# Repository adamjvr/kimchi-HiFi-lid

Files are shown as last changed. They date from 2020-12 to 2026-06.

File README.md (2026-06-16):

# Kimchi HiFi Lid — SGTL PCB

This directory contains the KiCad hardware files for the **SGTL5000-based audio PCB variant** of the Kimchi HiFi Lid project.

The board is an audio codec / interface PCB intended to mate with the main Kimchi hardware through high-density board-to-board connectors. It includes the audio codec, clocking, analog I/O connectors, EEPROM, local power filtering, and supporting passives required for the SGTL audio path.

## Design overview

Primary design intent:

- Provide a compact audio codec board for the Kimchi HiFi Lid assembly.
- Interface the audio codec and related signals to the parent system through two 60-pin Hirose board-to-board connectors.
- Break out analog audio through RCA and 3.5 mm audio connectors.
- Provide local clocking, EEPROM, level/interface support, and power filtering around the codec.

## Main functional blocks

- **Audio codec:** `U2` — `SGTL5000XNLA3`, NXP SGTL5000 stereo audio codec.
- **Clock source:** `X1` — `ASFL1-12.288MHZ-EC-T`, 12.288 MHz oscillator.
- **EEPROM:** `U1` — `24C32` / `M24C32-FMC6TG` I²C EEPROM.
- **Board-to-board connectors:** `J2`, `J3` — `DF40HC(3.5)-60DS` 60-pin connectors.
- **Analog audio I/O:**
  - `J1`, `J4` — `RCJ-2123` RCA jacks.
  - `J5` — `54-00176` 3.5 mm audio jack.
  - `MIC_IN` and `MIC_BIAS` nets for microphone input support.
- **Logic support:** `U3` — `SN74LV1T34DBVRG4` single-bit buffer / level interface.
- **Power rails and filtering:** `VDD_5V`, `VDD_3V3`, `VDD_1V8`, ferrite beads, bulk capacitance, and local bypassing.

## Directory contents

| Path | Purpose |
|---|---|
| `kimchi_ulid.sch` | Main KiCad / Eeschema schematic. |
| `kimchi_ulid.sch-bak` | Backup copy of the schematic. |
| `kimchi_ulid.lib` | Local symbol library. |
| `kimchi_ulid-cache.lib` | Cached schematic symbols. |
| `kimchi_ulid.dcm` | KiCad symbol documentation metadata. |
| `kimchi_ulid.csv` | BOM / component export. See warning below before ordering. |
| `kimchi_ulid.xml` | KiCad-generated netlist / BOM source export. |
| `kimchi_ulid.pretty/` | Local KiCad footprints and related 3D assets. |
| `gerber/` | Exported manufacturing files. |
| `sym-lib-table` | KiCad symbol library table. |
| `fp-lib-table` | KiCad footprint library table. |

## KiCad version notes

This project uses the older KiCad / Eeschema file format, with the schematic stored as `kimchi_ulid.sch`.

For editing in a newer KiCad release:

1. Open the project/schematic in KiCad.
2. Let KiCad convert legacy schematic/library data if prompted.
3. Save the converted project on a new branch before overwriting the original files.
4. Re-run ERC, DRC, BOM export, and Gerber generation after conversion.

## Fabrication notes

The `gerber/` directory contains exported fabrication data, including copper, solder mask, silkscreen, fabrication, and edge-cut files.

Before sending this board out for manufacture, regenerate the manufacturing package from the current KiCad project and verify:

- Board outline and mounting holes.
- Layer stackup, especially the inner copper layers.
- DF40 connector orientation, stack height, and mating-board alignment.
- RCA and 3.5 mm jack mechanical clearance.
- Power rail assignments from the parent board.
- Audio routing, grounding, and codec analog supply filtering.
- I²C / digital audio signal mapping to the parent processor.

## Important BOM warning

The schematic in this SGTL folder uses `SGTL5000XNLA3` for `U2`, but the checked-in `kimchi_ulid.csv` may be stale and may still list `U2` as `WM8750CJLGEFL` from an earlier codec revision.

Do **not** order directly from the CSV without regenerating the BOM from the current schematic.

Recommended release process:

1. Open the schematic in KiCad.
2. Confirm `U2` is the intended SGTL5000 part.
3. Regenerate the BOM / CSV from the active schematic.
4. Compare the regenerated BOM against the committed `kimchi_ulid.csv`.
5. Update the CSV before fabrication or assembly.

## Bring-up checklist

Suggested first-power and validation flow:

- Inspect the board for solder bridges, especially around the codec QFN and DF40 connectors.
- Verify no shorts on `VDD_5V`, `VDD_3V3`, `VDD_1V8`, and ground before power-up.
- Power the board from a current-limited bench supply or through the intended parent board with current monitoring.
- Confirm local rails are present and stable.
- Confirm the 12.288 MHz oscillator output.
- Verify I²C communication with the codec and EEPROM.
- Confirm codec reset / enable behavior if controlled by the parent system.
- Test analog output at low level first, then validate full-scale playback.
- Test microphone input and bias only after confirming the audio codec is enumerating/configuring correctly.

## Status

Hardware design files and generated manufacturing outputs are present, but this directory should be treated as an engineering design package rather than a guaranteed production release. Regenerate and review all release outputs before ordering boards or parts.

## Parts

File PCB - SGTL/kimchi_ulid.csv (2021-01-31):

Reference | Quantity | Value | Footprint | Datasheet | Mfgr | Part | Vendorpart | Cost QTY: 1 | Cost QTY: 1000 | Cost QTY: 10000 | Cost QTY: 2500 | Cost QTY: 5000 | Date Created | Date Modified | Description | Designer | Height | Lead-Free ? | MFR | MFR# | Management_ID | Mounting | Package | Pin Count # | RoHS Levels | Status | Tolerance | Type | Vendor | Vendor # | Voltage | _Value_ | Cost QTY: 3000
C10 C12 | 2 | T491D227M010AT | kimchi_ulid:T491D227M010AT | https://api.kemet.com/component-edge/download/datasheet/T491D227M010AT.pdf |  |  |  | 1.36000 | 0.53786 | * | 0.50200 | 0.48408 | 12/16/2020 | 12/16/2020 | 220µF Molded Tantalum Capacitors 10V 2917 (7343 Metric) 500mOhm | AVR | 3.10mm | Yes | KEMET | T491D227M010AT | * | SMT | 2917 | 2 | 1 | Active | 10% | Tantalum Cap | Digikey | 399-9744-2-ND | 10VDC | 220uF
C1 C2 C15 C16 C17 | 5 | T491A105K010AT | kimchi_ulid:C1206 | https://www.digikey.com/htmldatasheets/production/2487974/0/0/1/t491-series.html |  |  |  | 0.30000 | 0.07980 | 0.06720 | * | * | 12/9/2020 | 12/9/2020 | 1µF Molded Tantalum Capacitors 10V 1206 (3216 Metric) | AVR | 0.55mm | Yes | KEMET | T491A105K010AT | * | SMT | 1206 | 2 | 1 | Active | 10% | Ceramic Cap | Digikey | 399-9449-2-ND | 10V | 1uF
C25 | 1 | UZP1H0R1MCL1GB | kimchi_ulid:UZP1H0R1MCL1GB | https://media.digikey.com/pdf/Data%20Sheets/Nichicon%20PDFs/ZP_Series.pdf |  |  |  | 0.71000 | 0.20706 | 0.17052 | * | * | 12/16/2020 | 12/16/2020 | 0.1µF 50V Aluminum Electrolytic Capacitors Radial, Can - SMD 2000 Hrs @ 85°C | AVR | 4.6mm | Yes | Nichicon | UZP1H0R1MCL1GB | * | SMT | * | 2 | 1 | Active | 20% | Aluminum Cap | Digikey | 493-10087-2-ND | 50V | 0.1uF
C3 C4 C5 C6 C7 C8 C11 C14 C18 C24 | 10 | C0402C104K9PACTU | kimchi_ulid:C0402 | https://content.kemet.com/datasheets/KEM_C1006_X5R_SMD.pdf |  |  |  | 0.10000 | 0.01139 | 0.00756 | 0.01035 | 0.00952 | 12/7/2019 | 12/7/2019 | 0.1µF ±10% 6.3V Ceramic Capacitor X5R 0402 (1005 Metric) | AVR | 0.55mm | Yes | KEMET | C0402C104K9PACTU | * | SMT | 0402 | 2 | 1 | Active | 10% | Ceramic Cap | Digikey | 399-3026-6-ND | 6.3V | 0.1uF
C9 C13 C19 C20 C21 C22 C23 | 7 | T494A106M006AT | kimchi_ulid:T494A106M006AT | https://api.kemet.com/component-edge/download/datasheet/T494A106M006AT.pdf |  |  |  | 0.69000 | 0.23100 | * | 0.23100 | * | 12/16/2020 | 12/16/2020 | 10µF Molded Tantalum Capacitors 6.3V 1206 (3216 Metric) 2Ohm | AVR | 1.8mm | Yes | KEMET | T494A106M006AT | * | SMT | 1206 | 2 | 1 | Active | 20% | Tantalum Cap | Digikey | 399-9757-2-ND | 6.3V | 10uF
FB1 FB2 FB3 FB4 FB5 FB6 FB7 | 7 | FBMJ1608HM180NTR | kimchi_ulid:R0603 | https://www.yuden.co.jp/productdata/catalog/chipbeads01_e.pdf |  |  |  | 0.11000 | 0.03135 | * | 0.02660 | 0.02850 | 12/5/2019 | 12/5/2019 | 18 Ohms @ 100MHz 1 Power Line Ferrite Bead 0603 (1608 Metric) 7.5A 4mOhm | AVR | 1mm | Yes | Taiyo Yuden | FBMJ1608HM180NTR | * | SMT | 0603 | 2 | 1 | Active | * | Ferrite Bead | Digikey | 587-3251-1-ND | * | FBMJ1608HM180NTR
H1 H2 H3 H4 | 4 | MountingHole_Pad | kimchi_ulid:MountingHole_3mm_Pad | ~
J1 J4 | 2 | RCJ-2123 | kimchi_ulid:RCJ-2123 | https://www.cuidevices.com/product/resource/digikeypdf/rcj-21xx.pdf |  |  |  | 1.67000 | 0.93000 | * | 0.86800 | * | 12/14/2020 | 12/14/2020 | 3.20mm ID, 9.00mm OD (RCA) Phono (RCA) Jack Mono Connector Solder | AVR | 5.12mm | Yes | CUI Devices | RCJ-2123 | * | ThroughHole Right Angle | * | 4 | 1 | Active | * | RCA Jack | Digikey | CP-1432-ND | 24VDC | RCJ-2123
J2 J3 | 2 | DF40HC(3.5)-60DS | kimchi_ulid:DF40HC(3.5)-60DS | ~
J5 | 1 | 54-00176 | kimchi_ulid:54-00176 | http://www.kycon.com/2013Catalogpage/USB/KUSBX.pdf |  |  |  | 0.91000 | 0.49600 | 0.41230 |  | 0.43400 | 12/8/2020 | 12/8/2020 | 3.50mm (0.141 | 1/8" | Mini Plug) - Headphone Phone Jack Stereo (4 Conductor | TRRS) Connector Solder" | AVR | 4mm | Yes | Tensility International Corp | 54-00176 | * | ThroughHole Right Angle | 3.5mm Audio | 6 | 1 | Active | * | 3.5mm Audio | Digikey | 839-54-00176TR-ND | * | 54-00176 | 0.44950
J6 | 1 | Conn_01x03_Male | Pin_Headers:Pin_Header_Straight_1x03_Pitch2.54mm | ~
LOGO1 | 1 | Logo_Open_Hardware_Small | Symbol:OSHW-Logo_5.7x6mm_SilkScreen | ~
R1 | 1 | RC0402JR-072K2L | AVR-KiCAD-Lib-Resistors:R0402 | https://www.yageo.com/upload/media/product/productsearch/datasheet/rchip/PYu-RC_Group_51_RoHS_L_11.pdf |  |  |  | 0.10000 | 0.00212 | 0.00132 | 0.00184 | 0.00152 | 12/10/2020 | 12/10/2020 | 2.2 kOhms ±5% 0.063W, 1/16W Chip Resistor 0402 (1005 Metric) Thick Film | AVR | 0.4mm | Yes | Yageo | RC0402JR-072K2L | * | SMT | 0402 | 2 | 1 | Active | 1% | Thick Film Resistor | Digikey | 311-2.2KJRCT-ND | * | 2.2K
R2 | 1 | RC0603FR-0747KL | AVR-KiCAD-Lib-Resistors:R0603 | https://www.yageo.com/upload/media/product/productsearch/datasheet/rchip/PYu-RC_Group_51_RoHS_L_10.pdf |  |  |  | 0.10000 | 0.00421 | 0.00238 | 0.00366 | 0.00274 | 6/18/2020 | 6/18/2020 | 47 kOhms ±1% 0.1W, 1/10W Chip Resistor 0603 (1608 Metric) Moisture Resistant Thick Film | AVR | 0.55m | Yes | Yageo | RC0603FR-0747KL | * | SMT | 0603 | 2 | 1 | Active | 1% | Resistor | Digikey | 311-47.0KHRCT-ND | * | 47K
U1 | 1 | 24C32 | Package_DFN_QFN:DFN-8-1EP_3x2mm_P0.5mm_EP1.36x1.46mm | http://www.st.com/content/ccc/resource/technical/document/datasheet/80/4e/8c/54/f2/63/4c/4a/CD00001012.pdf/files/CD00001012.pdf/jcr:content/translations/en.CD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 | ST | M24C32-FMC6TG | 497-15757-1-ND
U2 | 1 | WM8750CJLGEFL | kimchi_ulid:QFN-32_EP_5x5_Pitch0.5mm | https://d3uzseaevmutz1.cloudfront.net/pubs/proDatasheet/WM8750JL_v4.1.pdf |  |  |  | 5.59000 | 2.80630 | * | 2.70080 | 2.61640 | 12/15/2020 | 12/15/2020 | Stereo Audio Interface 24 b 32-QFN (5x5) | AVR | 1.1mm | Yes | Cirrus Logic Inc. | WM8750CJLGEFL | * | SMT | QFN | 32 | 1 | Active | * | Audio Codec | Digikey | 598-2392-ND | 3.3V | WM8750CJLGEFL
U3 | 1 | SN74LV1T34DBVRG4 | kimchi_ulid:SOT-23-5 | http://www.ti.com/general/docs/suppproductinfo.tsp?distId=10 |  |  |  | 0.45000 | 0.14040 | * |  | * | 12/10/2020 | 12/10/2020 | Buffer, Non-Inverting 1 Element 1 Bit per Element Push-Pull Output SOT-23-5 | AVR | 1.11mm | Yes | Texas Instruments | SN74LV1T34DBVRG4 | * | SMT | SOT23-5 | 5 | 1 | Active | * | Buffer | Digikey | 296-SN74LV1T34DBVRG4CT-ND | 3.3V | SN74LV1T34DBVRG4 | 0.12870
X1 | 1 | ASFL1-12.288MHZ-EC-T | kimchi_ulid:ASFL1 | https://abracon.com/Oscillators/ASFL1.pdf |  |  |  | 1.14000 | 0.75048 | 0.66144 | * | 0.68688 | 12/10/2020 | 12/10/2020 | 12.288MHz XO (Standard) HCMOS, TTL Oscillator 3.3V Enable/Disable 4-SMD, No Lead | AVR | 4.4mm | Yes | Abracon LLC | ASFL1-12.288MHZ-EC-T | * | SMT | Proprietary | 4 | 1 | Active | * | Crystal | Digikey | 300-8245-1-ND | 3.3V | ASFL1-12.288MHZ-EC-T

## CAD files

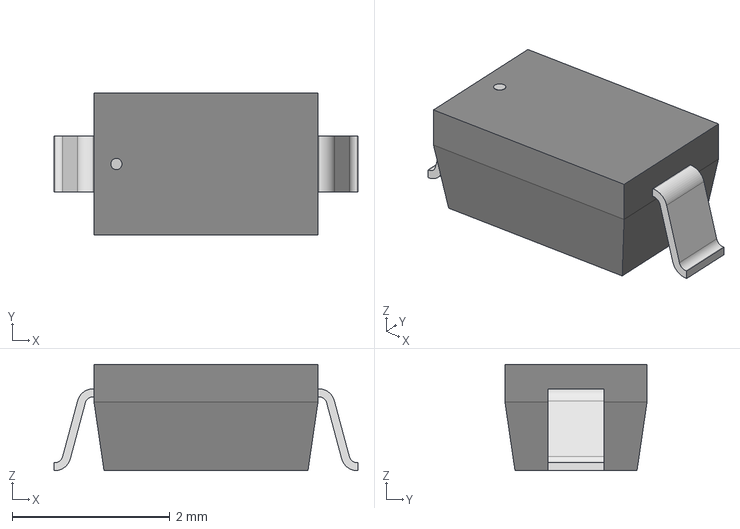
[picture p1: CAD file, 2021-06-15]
PCB - SGTL/3D/SOD-123_ONS.step
3.86 x 1.80 x 1.35 mm

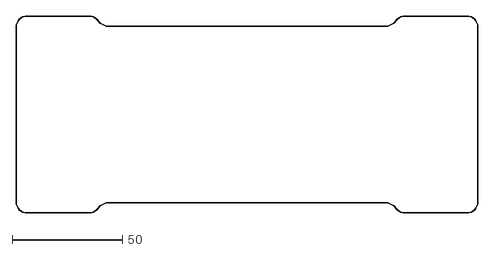
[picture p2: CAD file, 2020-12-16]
PCB - SGTL/Shape_Mockup.dxf
209.3 x 89.3

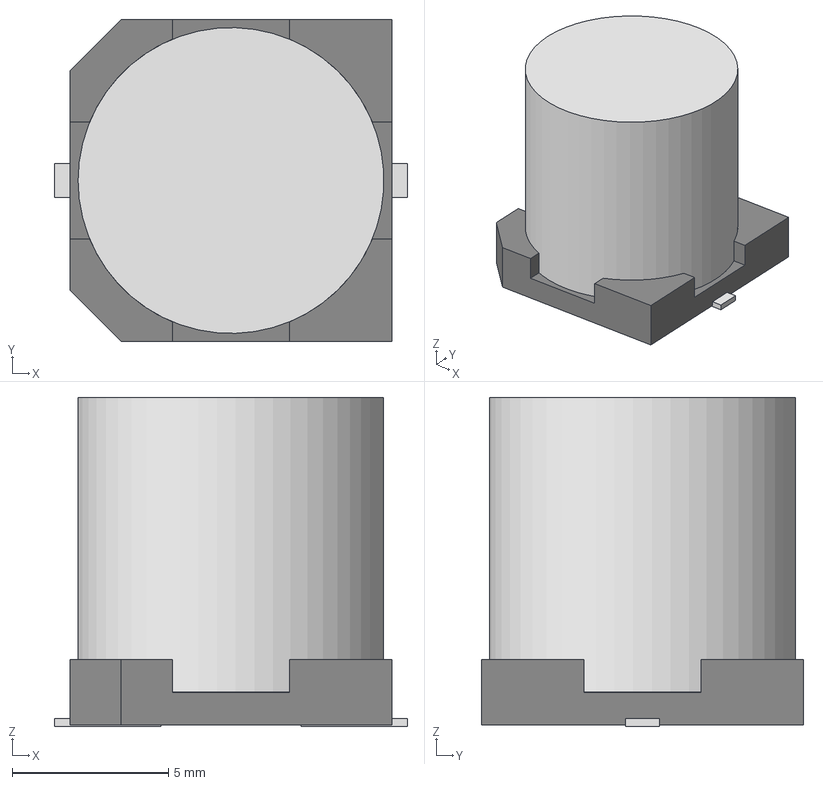
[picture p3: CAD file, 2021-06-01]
PCB - SGTL/3D/CAP_UCD_10X10_NCH.step
11.3 x 10.3 x 10.5 mm

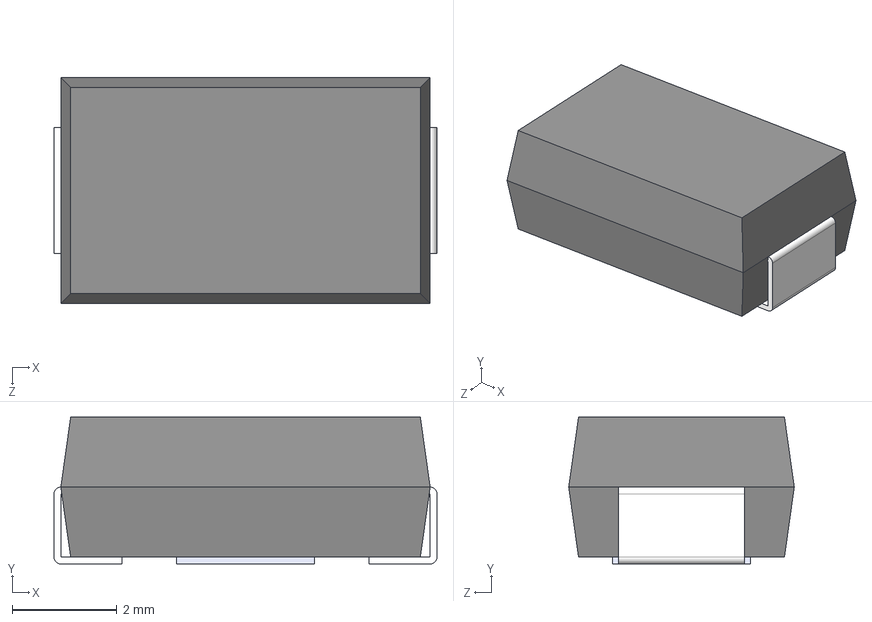
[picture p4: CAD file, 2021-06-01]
PCB - SGTL/3D/T491D106K020AT.STEP
7.30 x 2.80 x 4.30 mm

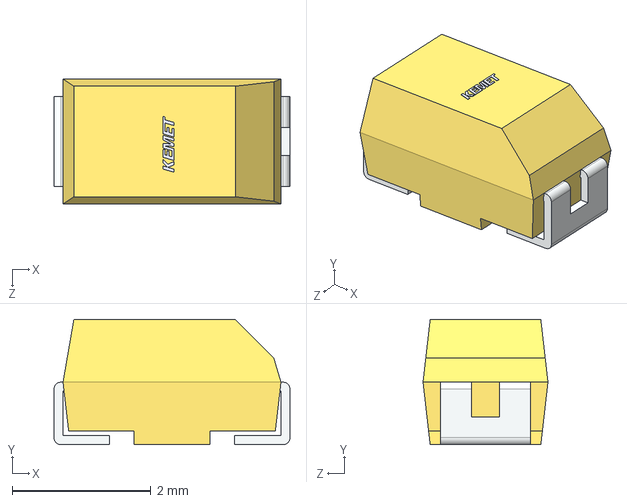
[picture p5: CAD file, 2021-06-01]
PCB - SGTL/3D/CTSM_TCM2NK_3216_L3.STEP
3.40 x 1.81 x 1.80 mm

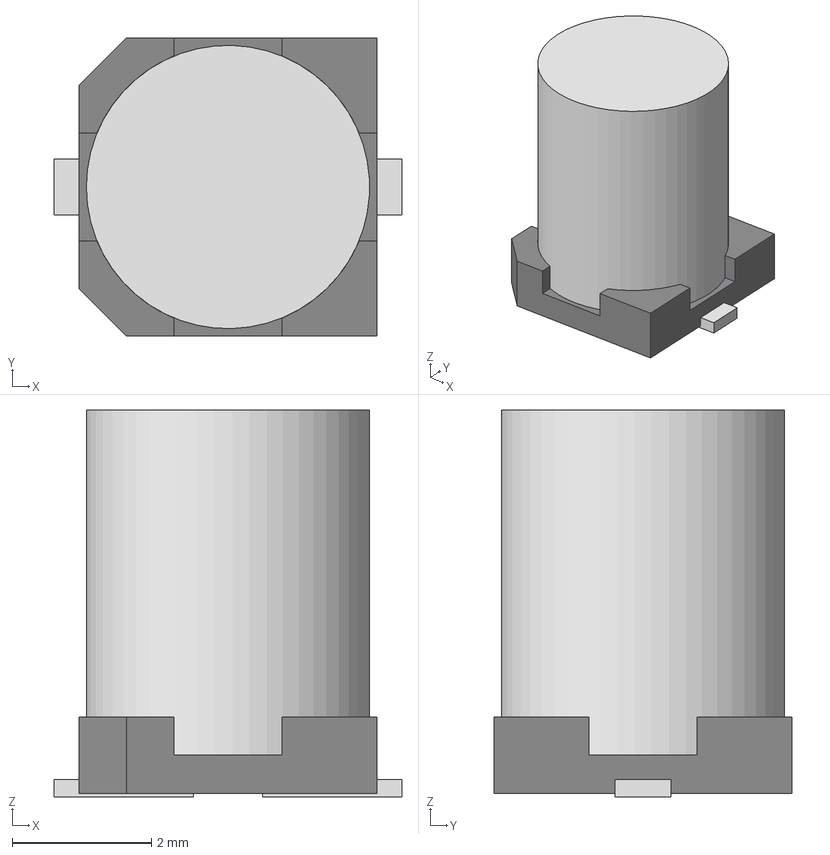
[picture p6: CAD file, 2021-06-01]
PCB - SGTL/3D/CAP_UUQ_4X5P4_NCH.step
5.00 x 4.29 x 5.57 mm

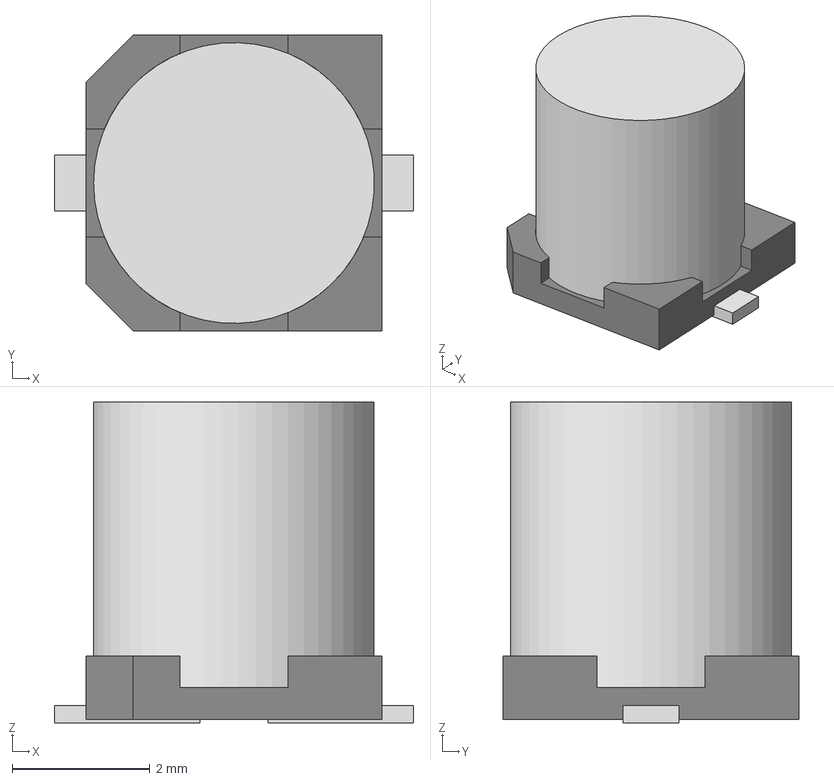
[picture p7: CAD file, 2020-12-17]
PCB - SGTL/3D/CAP_UZP_4X4P5_NCH.step
5.21 x 4.29 x 4.65 mm

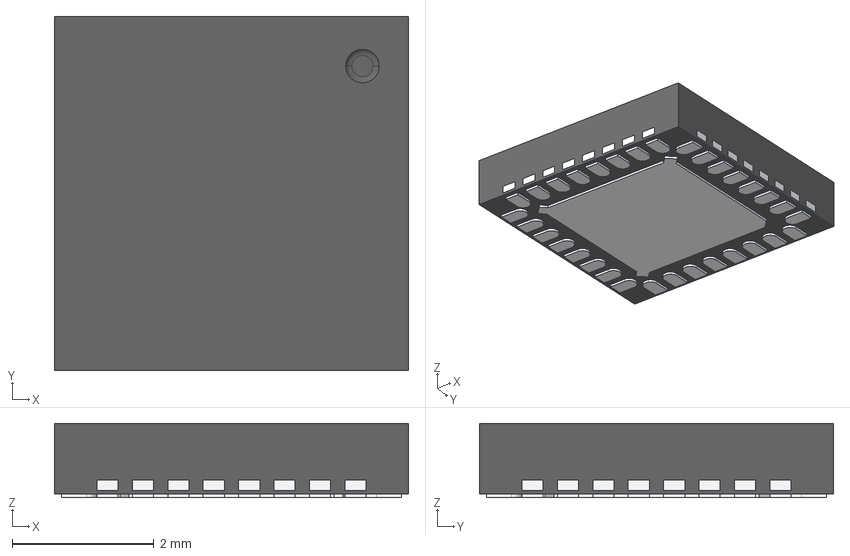
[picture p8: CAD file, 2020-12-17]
PCB - SGTL/3D/QFN-32 V6.stp
5.00 x 5.00 x 1.05 mm

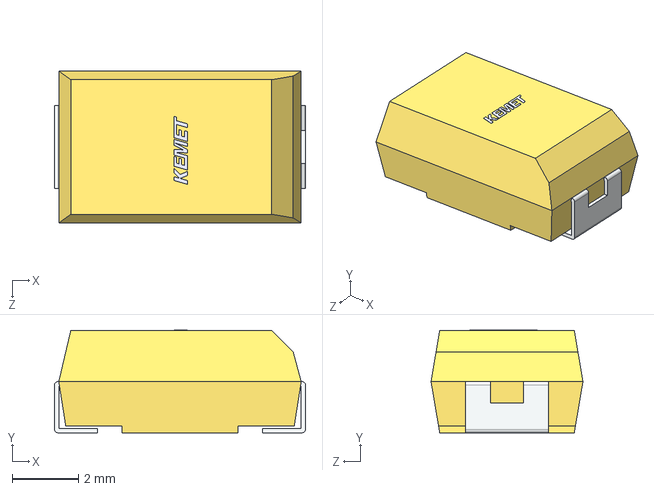
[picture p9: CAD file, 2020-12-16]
PCB - SGTL/3D/CTSM_TCM2NK_7343_L7.STEP
7.60 x 3.11 x 4.60 mm

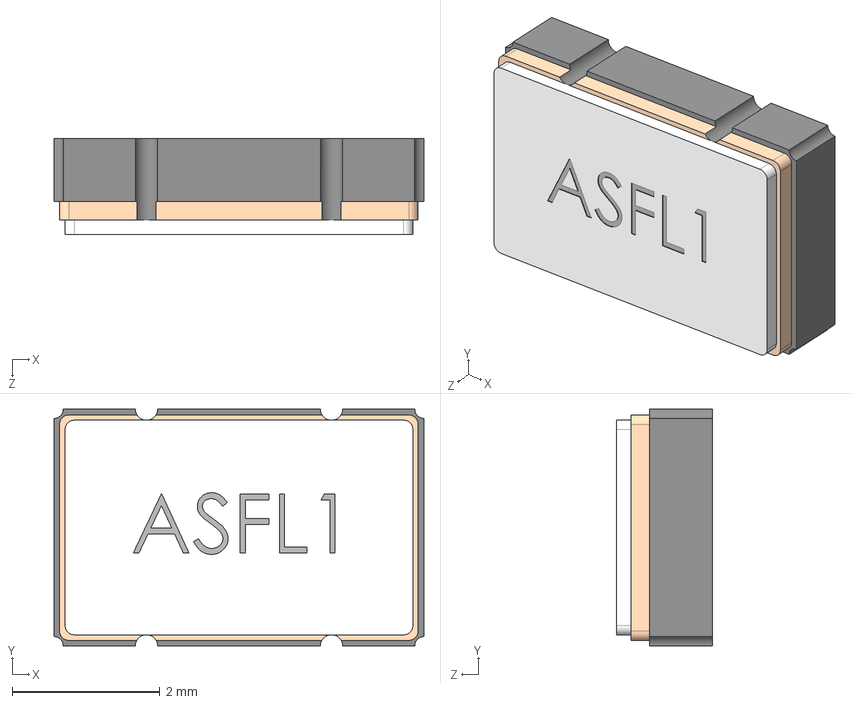
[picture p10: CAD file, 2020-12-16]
PCB - SGTL/3D/ASFL1.STEP
5.00 x 3.20 x 1.30 mm

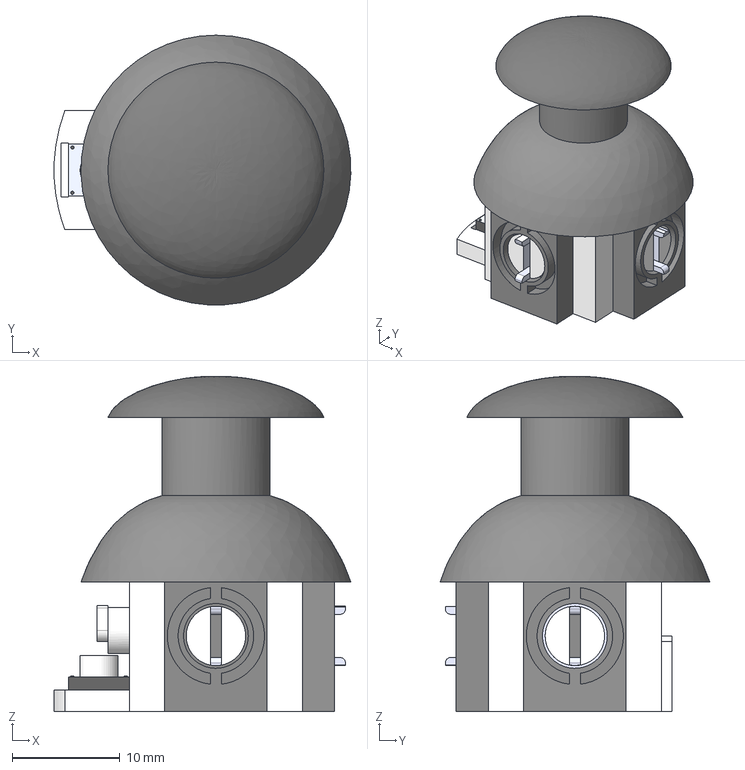
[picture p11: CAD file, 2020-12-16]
PCB - SGTL/3D/Joystick HW504 Board.step
27.5 x 25.0 x 31.0 mm

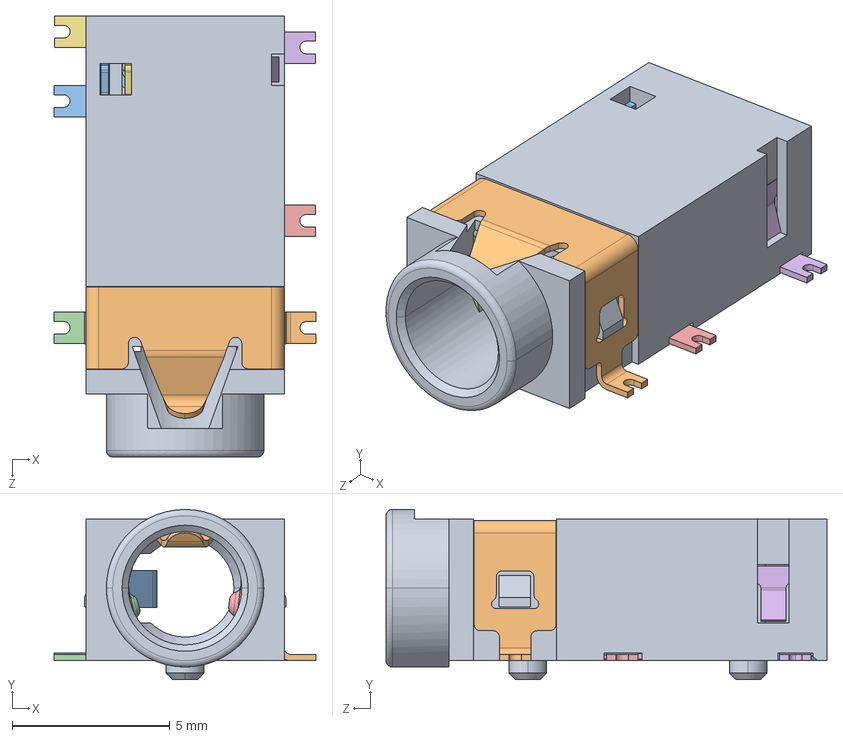
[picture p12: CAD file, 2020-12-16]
PCB - SGTL/3D/54-00177.STEP
8.31 x 5.40 x 14.0 mm
54-00177_insulator
54-00177_#1
54-00177_#4
54-00177_#2
54-00177_#3
54-00177_#6
54-00177_#5

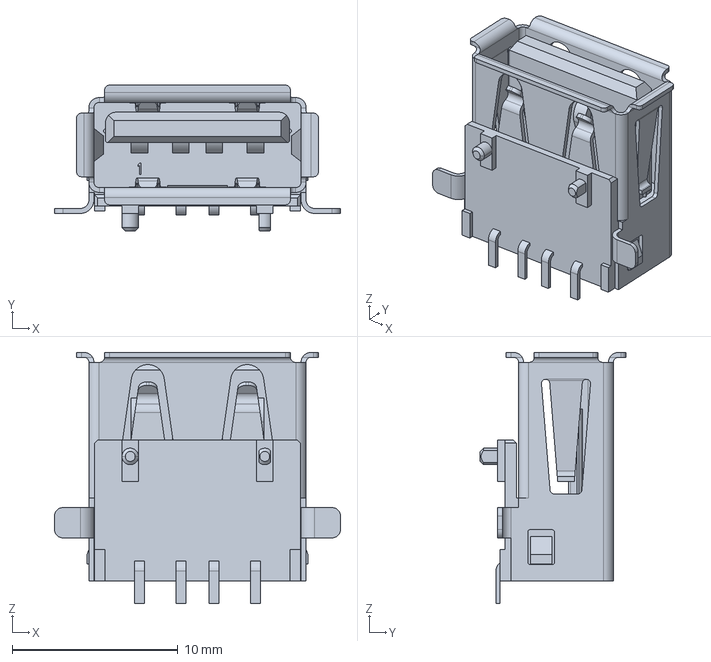
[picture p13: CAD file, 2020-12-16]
PCB - SGTL/3D/1-292303-6.stp
17.3 x 8.79 x 15.2 mm

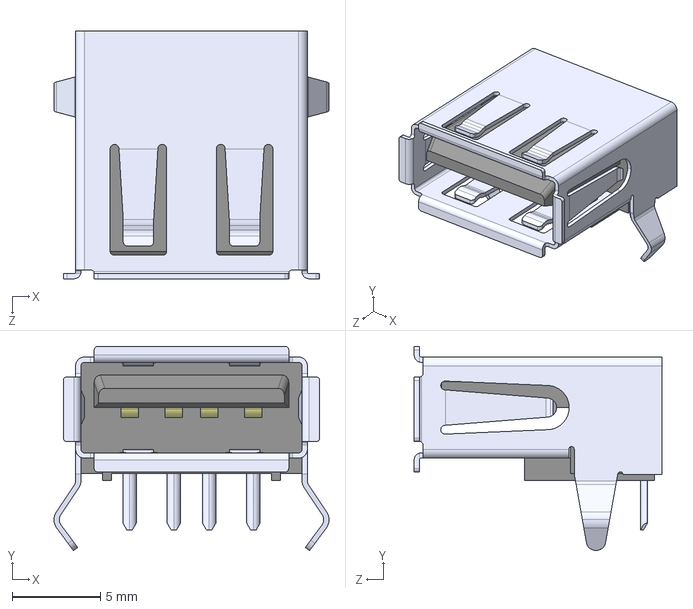
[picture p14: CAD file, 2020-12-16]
PCB - SGTL/3D/KUSBX-AS1N-B_A.STEP
15.5 x 11.5 x 14.0 mm

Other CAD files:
PCB - SGTL/3D/54-00176.STEP
PCB - SGTL/3D/CUI_DEVICES_RCJ-2123.step
PCB - SGTL/3D/SGTL5000XNLA3.STEP

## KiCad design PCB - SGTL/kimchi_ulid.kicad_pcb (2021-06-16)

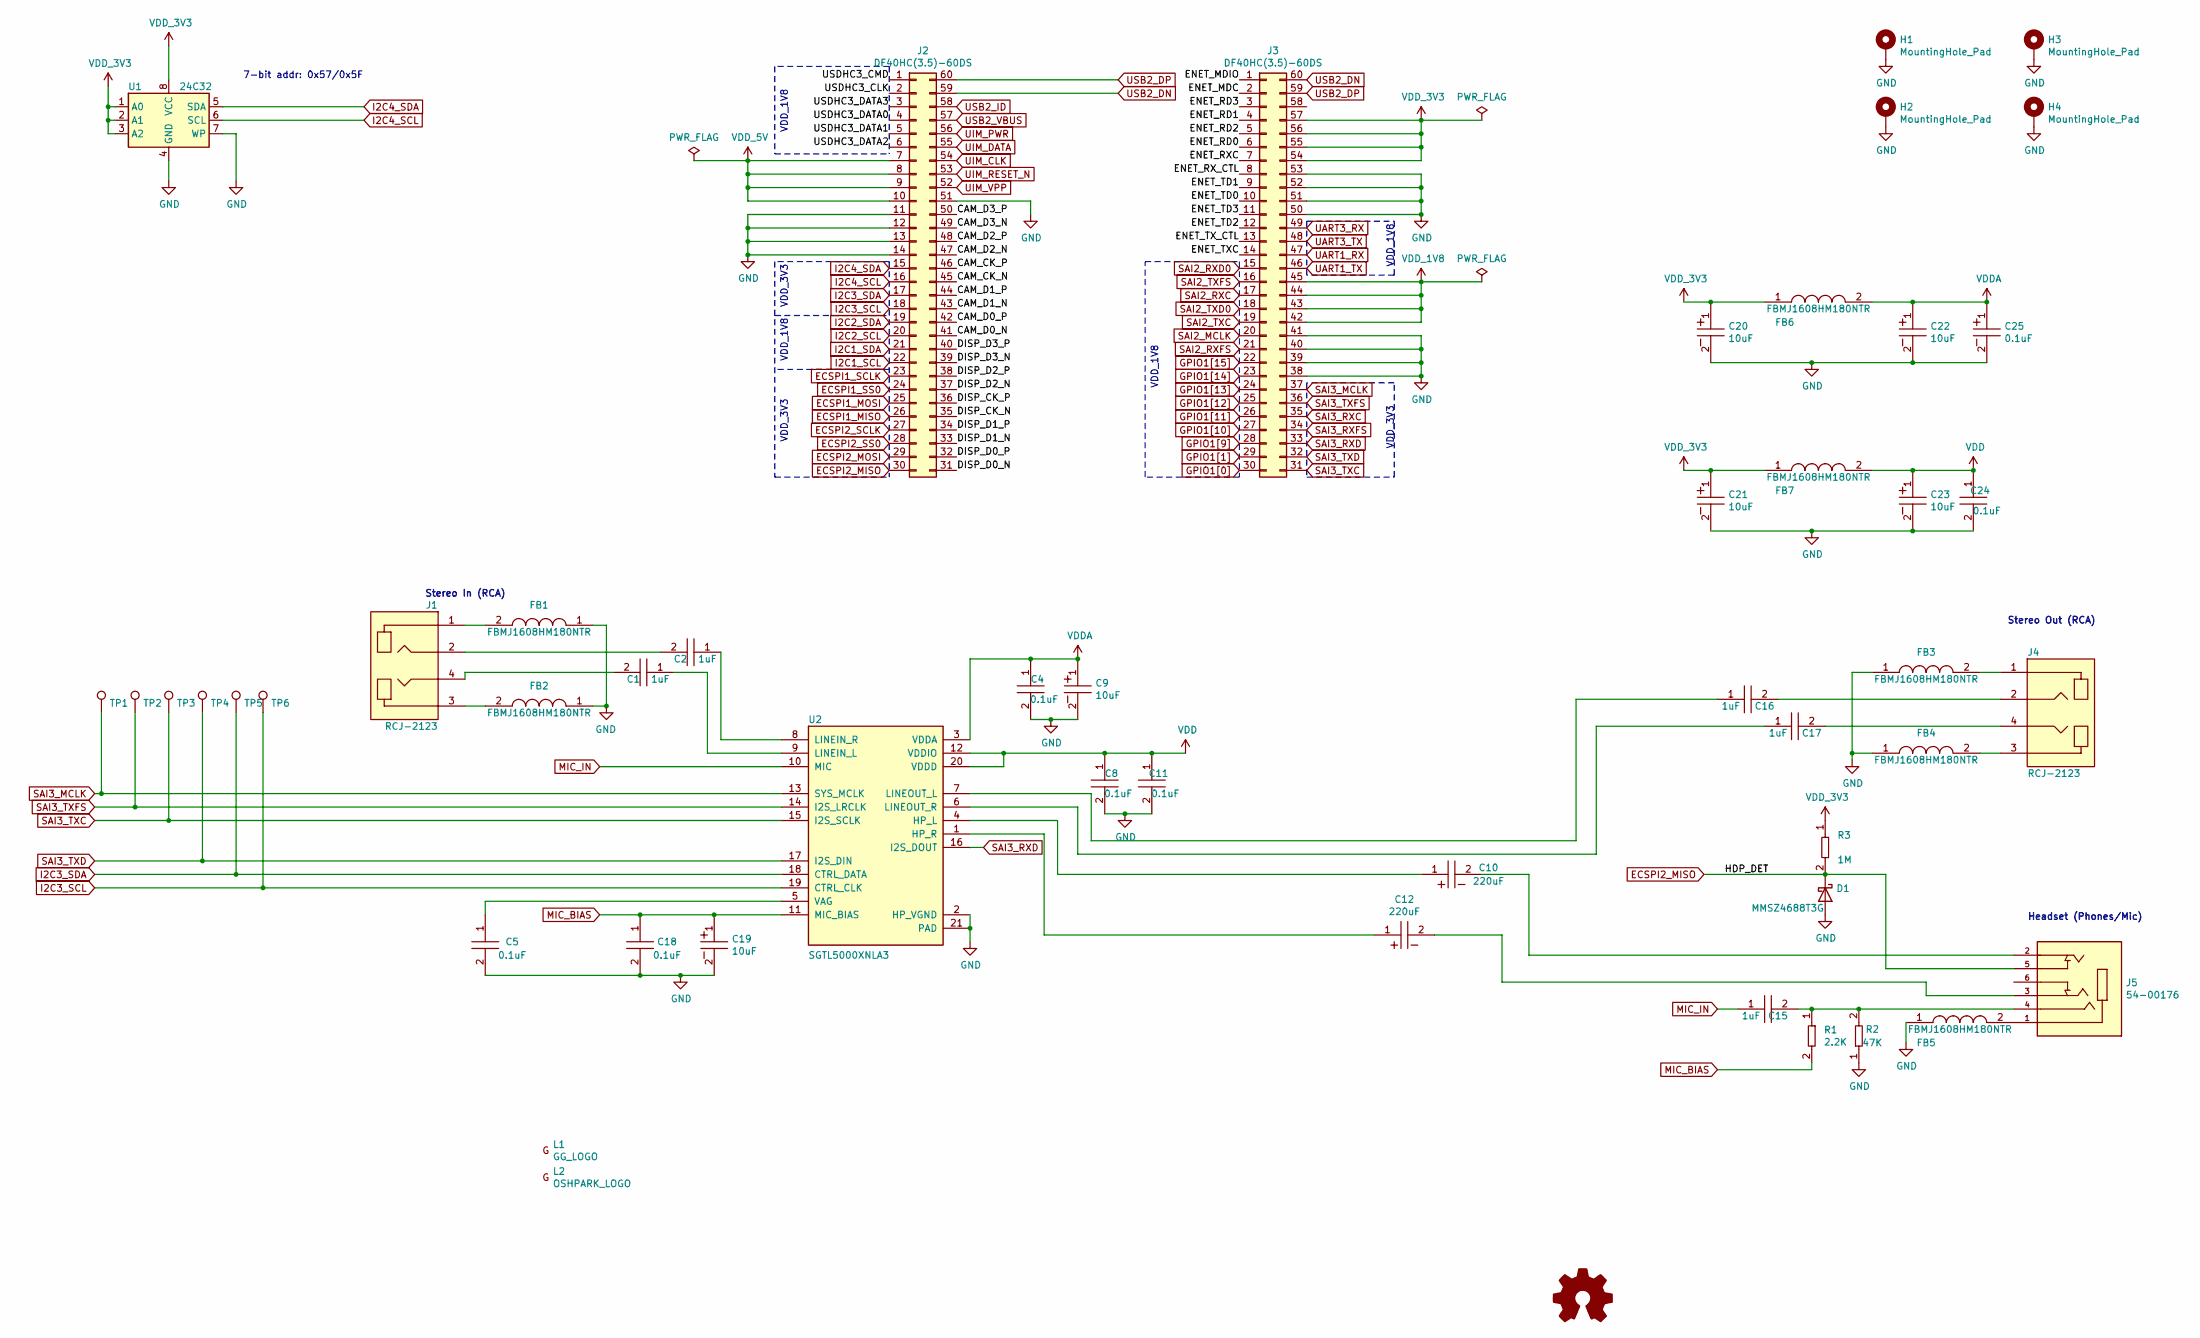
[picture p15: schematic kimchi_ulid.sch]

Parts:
C1, C2, C15, C16, C17: T491A105K010AT; C1206; Tolerance 10%; Voltage 10V; MFR# T491A105K010AT
C4, C5, C8, C11, C18, C24: C0402C104K9PACTU; C0402; Tolerance 10%; Voltage 6.3V; MFR# C0402C104K9PACTU
C9, C19, C20, C21, C22, C23: T494A106M006AT; Tolerance 20%; Voltage 6.3V; MFR# T494A106M006AT
C10, C12: T491D227M010AT; Tolerance 10%; Voltage 10VDC; MFR# T491D227M010AT
C25: UZP1H0R1MCL1GB; Tolerance 20%; Voltage 50V; MFR# UZP1H0R1MCL1GB
D1: MMSZ4688T3G
FB1, FB2, FB3, FB4, FB5, FB6, FB7: FBMJ1608HM180NTR; R0603; Tolerance *; Voltage *; MFR# FBMJ1608HM180NTR
H1, H2, H3, H4: MountingHole_Pad; MountingHole_3mm_Pad
J1, J4: RCJ-2123; Tolerance *; Voltage 24VDC; MFR# RCJ-2123
J2, J3: DF40HC(3.5)-60DS
J5: 54-00176; Tolerance *; Voltage *; MFR# 54-00176
L1: GG_LOGO; groupgets_logo
L2: OSHPARK_LOGO; oshpark_logo
LOGO1: Logo_Open_Hardware_Small; OSHW-Logo_5.7x6mm_SilkScreen
R1: RC0402JR-072K2L; R0402; Tolerance 1%; Voltage *; MFR# RC0402JR-072K2L
R2: RC0603FR-0747KL; R0603; Tolerance 1%; Voltage *; MFR# RC0603FR-0747KL
R3: AC0402FR-071ML; R0402; Tolerance 1%; Voltage *; MFR# AC0402FR-071ML
TP1, TP2, TP3, TP4, TP5, TP6: TestPoint; TestPoint_Pad_D1.0mm
U1: 24C32; DFN-8-1EP_3x2mm_P0.5mm_EP1.36x1.46mm; Part M24C32-FMC6TG
U2: SGTL5000XNLA3; QFN40P300X300X60-21N; Tolerance *; Voltage 3.3V; MFR# SGTL5000XNLA3

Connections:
/CAM_CK_N: J2.45
/CAM_CK_P: J2.46
/CAM_D0_N: J2.41
/CAM_D0_P: J2.42
/CAM_D1_N: J2.43
/CAM_D1_P: J2.44
/CAM_D2_N: J2.47
/CAM_D2_P: J2.48
/CAM_D3_N: J2.49
/CAM_D3_P: J2.50
/DISP_CK_N: J2.35
/DISP_CK_P: J2.36
/DISP_D0_N: J2.31
/DISP_D0_P: J2.32
/DISP_D1_N: J2.33
/DISP_D1_P: J2.34
/DISP_D2_N: J2.37
/DISP_D2_P: J2.38
/DISP_D3_N: J2.39
/DISP_D3_P: J2.40
/ENET_MDC: J3.2
/ENET_MDIO: J3.1
/ENET_RD0: J3.6
/ENET_RD1: J3.4
/ENET_RD2: J3.5
/ENET_RD3: J3.3
/ENET_RXC: J3.7
/ENET_RX_CTL: J3.8
/ENET_TD0: J3.10
/ENET_TD1: J3.9
/ENET_TD2: J3.12
/ENET_TD3: J3.11
/ENET_TXC: J3.14
/ENET_TX_CTL: J3.13
/USDHC3_CLK: J2.2
/USDHC3_CMD: J2.1
/USDHC3_DATA0: J2.4
/USDHC3_DATA1: J2.5
/USDHC3_DATA2: J2.6
/USDHC3_DATA3: J2.3
ECSPI1_MISO: J2.26
ECSPI1_MOSI: J2.25
ECSPI1_SCLK: J2.23
ECSPI1_SS0: J2.24
ECSPI2_MISO: D1.1 (K), J2.30, J5.5, R3.2
ECSPI2_MOSI: J2.29
ECSPI2_SCLK: J2.27
ECSPI2_SS0: J2.28
GND: C4.2, C5.2, C8.2, C9.2, C11.2, C18.2, C19.2, C20.2, C21.2, C22.2, C23.2, C24.2, C25.2, D1.2 (A), FB1.1, FB2.1, FB3.1, FB4.1, FB5.1, H1.1, H2.1, H3.1, H4.1, J2.11, J2.12, J2.13, J2.14, J2.51, J3.38, J3.39, J3.40, J3.41, J3.50, J3.51, J3.52, J3.53, R2.1, U1.4 (GND), U1.7 (WP), U2.2 (HP_VGND), U2.21 (PAD)
GPIO1[0]: J3.30
GPIO1[1]: J3.29
GPIO1[9]: J3.28
GPIO1[10]: J3.27
GPIO1[11]: J3.26
GPIO1[12]: J3.25
GPIO1[13]: J3.24
GPIO1[14]: J3.23
GPIO1[15]: J3.22
I2C1_SCL: J2.22
I2C1_SDA: J2.21
I2C2_SCL: J2.20
I2C2_SDA: J2.19
I2C3_SCL: J2.18, TP6.1, U2.19 (CTRL_CLK)
I2C3_SDA: J2.17, TP5.1, U2.18 (CTRL_DATA)
I2C4_SCL: J2.16, U1.6 (SCL)
I2C4_SDA: J2.15, U1.5 (SDA)
MIC_BIAS: C18.1, C19.1, R1.2, U2.11 (MIC_BIAS)
MIC_IN: C15.1, U2.10 (MIC)
unnamed: C1.1, U2.9 (LINEIN_L)
unnamed: C1.2, J1.4
unnamed: C2.1, U2.8 (LINEIN_R)
unnamed: C2.2, J1.2
unnamed: C5.1, U2.5 (VAG)
unnamed: C10.1, U2.4 (HP_L)
unnamed: C10.2, J5.2
unnamed: C12.1, U2.1 (HP_R)
unnamed: C12.2, J5.3
unnamed: C15.2, J5.4, R1.1, R2.2
unnamed: C16.2, J4.2
unnamed: C17.2, J4.4
unnamed: FB1.2, J1.1
unnamed: FB2.2, J1.3
unnamed: FB3.2, J4.1
unnamed: FB4.2, J4.3
unnamed: FB5.2, J5.1
SAI2_MCLK: J3.20
SAI2_RXC: J3.17
SAI2_RXD0: J3.15
SAI2_RXFS: J3.21
SAI2_TXC: J3.19
SAI2_TXD0: J3.18
SAI2_TXFS: J3.16
SAI3_MCLK: J3.37, TP1.1, U2.13 (SYS_MCLK)
SAI3_RXC: J3.35
SAI3_RXD: J3.33, U2.16 (I2S_DOUT)
SAI3_RXFS: J3.34
SAI3_TXC: J3.31, TP3.1, U2.15 (I2S_SCLK)
SAI3_TXD: J3.32, TP4.1, U2.17 (I2S_DIN)
SAI3_TXFS: J3.36, TP2.1, U2.14 (I2S_LRCLK)
UART1_RX: J3.47
UART1_TX: J3.46
UART3_RX: J3.49
UART3_TX: J3.48
UIM_CLK: J2.54
UIM_DATA: J2.55
UIM_PWR: J2.56
UIM_RESET_N: J2.53
UIM_VPP: J2.52
USB2_DN: J2.59, J3.60
USB2_DP: J2.60, J3.59
USB2_ID: J2.58
USB2_VBUS: J2.57
VDD: C8.1, C11.1, C23.1, C24.1, FB7.2, U2.12 (VDDIO), U2.20 (VDDD)
VDDA: C4.1, C9.1, C22.1, C25.1, FB6.2, U2.3 (VDDA)
VDD_1V8: J3.42, J3.43, J3.44, J3.45
VDD_3V3: C20.1, C21.1, FB6.1, FB7.1, J3.54, J3.55, J3.56, J3.57, R3.1, U1.1 (A0), U1.2 (A1), U1.3 (A2), U1.8 (VCC)
VDD_5V: J2.7, J2.8, J2.9, J2.10

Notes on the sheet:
7-bit addr: 0x57/0x5F
VDD_1V8
VDD_3V3
Headset (Phones/Mic)
Stereo Out (RCA)
Stereo In (RCA)

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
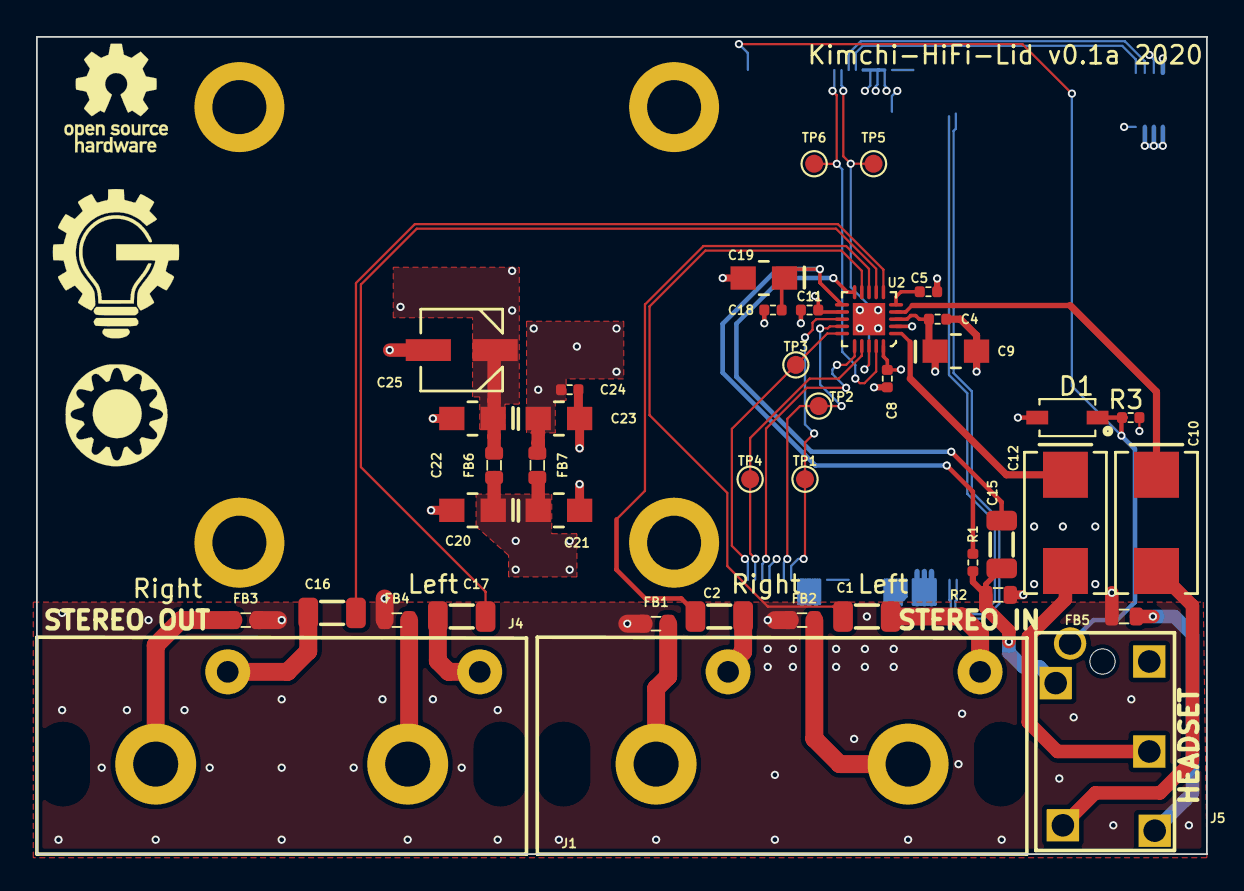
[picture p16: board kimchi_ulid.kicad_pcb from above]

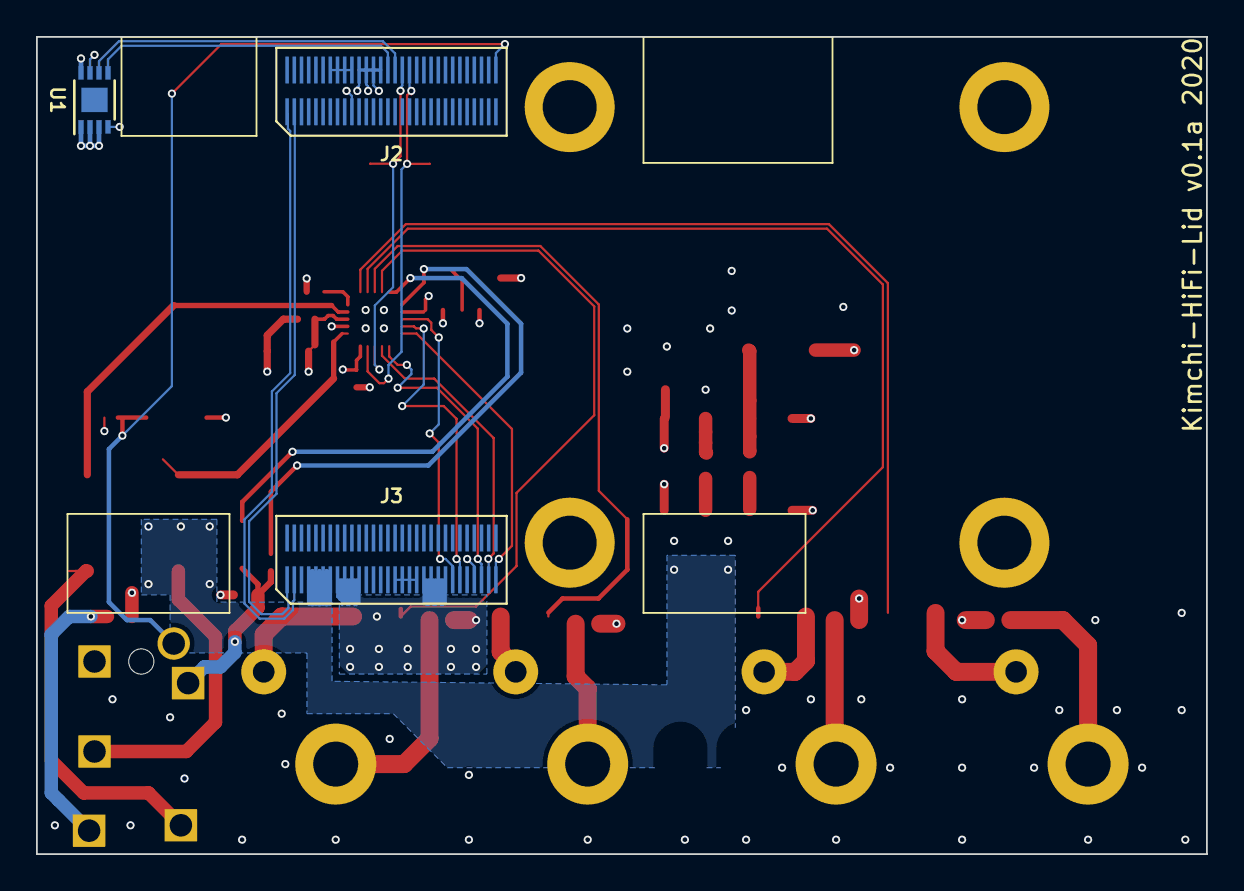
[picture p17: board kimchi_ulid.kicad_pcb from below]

Board: 4 copper layers, 65.0 x 45.4 mm, 51 parts (3 on the bottom side), 39 nets.

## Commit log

2020-12-16 Progress
    Board layout and shape defined, schematic in the process of rework, changing over to Wolfson DAC.
    [1-292303-6.stp, 54-00176.STEP, 54-00177.STEP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]
2020-12-16 redesigned circuit around WM8750 codec, added needed components to library
    [CAP_UCD_10X10_NCH.step, CAP_UUQ_4X5P4_NCH.step, CTSM_TCM2NK_3216_L3.STEP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]
2020-12-17 Route In Progress
    Now doing the intial route of the board, still very much a work in progress, have the pwoer planes figured out and general component placenment. All components now have 3D models.
    [CAP_UZP_4X4P5_NCH.step, QFN-32 V6.stp, kimchi_ulid.kicad_pcb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]
2020-12-23 First Route Pass Completed
    Completed first pass of routting the board. Need to adjust trace width for analog front ends for audio in and out.
    [kimchi_ulid.kicad_pcb, kimchi_ulid.sch]
2020-12-23 MCLK Jumper
    MCLK jumper added, trace width tweaked and DRC passed.
    [kimchi_ulid.kicad_pcb, kimchi_ulid.sch]
2020-12-29 MCLK Traces
    MCLK trace moved
    [kimchi_ulid.kicad_pcb]
2021-01-05 PCB tweaks
    fixed crooked board edge. Corrected board dimension labels. Moved board inside project so that bottom left corner is the origin.
    [kimchi_ulid.kicad_pcb]
2021-01-31 Fab FIles
    Fab files generated
    [kimchi_ulid-B_Cu.gbl, kimchi_ulid-B_Mask.gbs, kimchi_ulid-B_SilkS.gbo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]
2021-06-01 SGTL Version
    New version of lid with new codec from NXP, PCB is almost done, need to check scheamtic with mwelling before finalizing route.
    [1-292303-6.stp, 54-00176.STEP, 54-00177.STEP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]
2021-06-02 SGTL Version
    SGTL version finished, need feedback, chip is weird the route is too
    [kimchi_ulid.kicad_pcb, kimchi_ulid.sch]
2021-06-04 Test Points
    Test points added, also traces cleaned up and widened in places where more current capacity is required or appreciated.
    [kimchi_ulid.kicad_pcb, kimchi_ulid.sch]
2021-06-15 Headphone Detect and DRC
    Cleared DRC violations, added and implemented a headphone detect circuit.
    [SOD-123_ONS.step, kimchi_ulid.kicad_pcb, kimchi_ulid.sch]
2021-06-16 Channel Swap
    Swapped right and left channels on input, they were backwards. Changed soldermask rules so fab can make their own.
    [kimchi_ulid.kicad_pcb]
2026-06-16 Revise README for Kimchi HiFi Lid project
    Updated README to reflect new project details and design overview for the SGTL5000-based audio PCB variant.

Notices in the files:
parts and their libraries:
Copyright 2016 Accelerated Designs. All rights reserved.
